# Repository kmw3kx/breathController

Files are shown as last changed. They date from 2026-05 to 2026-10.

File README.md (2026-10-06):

# Breath Controller

This is my personal repository for my wind controller project in development to catalog my work.

## Table of Contents
- [Daisy EVI Progress](#daisy-evi-progress)
- [Prospectus Submission for STS 4500, Summer 2026](#prospectus-submission-for-sts-4500-summer-2026)
- [Summer 2026 Personal Work](#summer-2026-personal-work)
- [Submission for Final Project, MUSI 4610, Spring 2026](#submission-for-final-project-musi-4610-spring-2026)
    - [Mapping](#mapping)
    - [Wiring](#wiring)
    - [**Sound**](#sound)
    - [CAD](#cad)
- [Future Improvements](#future-improvements)
- [Work Log](#work-Log)

## Daisy EVI Progress

### Summer 2026
7/20/26 - I have been continuing development of this project in between taking classes and working at my summer internship. The current model is running off of a daisy microcontroller. I have also been developing a 3D-printed needle valve to be able to more finely adjust back pressure of the instrument. There have been thoughts of creating custom pcb's for this project, but I am thinking of first making a prototype before trying to generate something that could be easily recreated. Hence, I am also trying other methods of fabrication beyond 3D printing, such as vacuum thermal forming, woodworking, and perfboard. I am also pivoting from an fsr to using a joystick attached to the mouthpiece, as there are issues with 3D printing food-safe mouthpieces.

(Post pic of prototype here)

The main confusion with using plug data is writing the custom .json file for the hardware integration. json doesn't have built-in comment functionality, so I had to really dig for the resources for this. See [here.](https://github.com/Wasted-Audio/hvcc/tree/develop/hvcc/generators/c2daisy/json2daisy/)

Unfortunately, it does not have support for an option to program in single-pin capacitive touch, so we'll need to trick it with pd code using an in/out pair. 

They also seem to use the digital pin numberings for analog ins, so 15 instead of A0.

Switch has a pullup resistor functionality built into it, but it is unclear if encoder does or not. 

I was having an issue with the analog inputs not printing to serial correctly when I was trying to code it in plugdata. The issue was that the 2 grounds needed to be tied together. 

I also wasn't able to get the cap touch working, so I decided to pivot back to using the mpr121. I originally was trying to avoid it since it's extra money, but... it will just make everything better. It saves the processing power & just simplifies everything.

[Here's](https://github.com/jonwaterschoot/plugdata-daisy-simple/tree/main) a good repo for daisy plugdata stuff.

[Here's](https://wasted-audio.github.io/hvcc/latest/generators/daisy/) the official stuff for daisy.

[Here's the current daisy_json guide](https://github.com/Wasted-Audio/hvcc/blob/develop/docs/generators/daisy_json.md)

I'm having some trouble getting the daisy to work with the MPR121 in plugdata. The patchsizes are starting to get very big, so I think I need to start using the bootloader.
https://community.daisy.audio/t/small-big-and-huge/9176/2

Working within MIDI seems to be more reliable than with serial. Press the boot button after resetting to keep the daisy in bootloader mode. I'm now having an issue with finding it as a midi device tho. Let me troubleshoot with my mpkmini.

8/4/26 - New day, new toolchain apparently. Printing is now working, so let's try and make something happen.

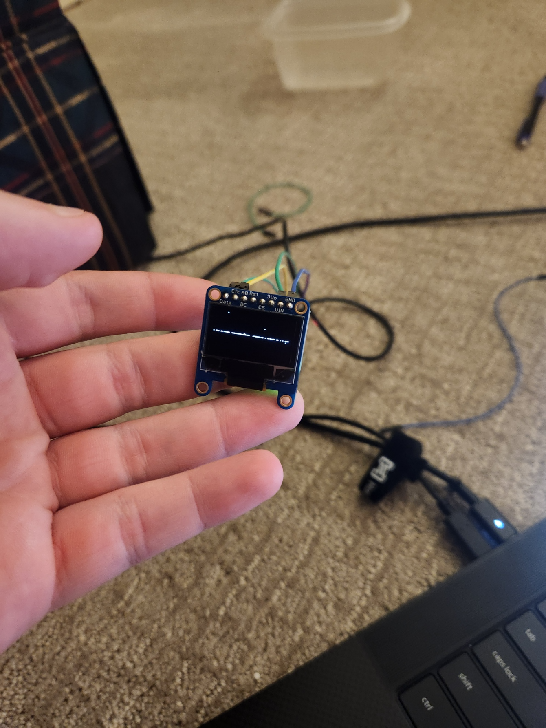
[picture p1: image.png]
DaisySeed3Pins


Idk why it's taken me this long to add this to my repo.

### Fall 2026

9/12/26 - Been busy with the start of the semester! Unfortunately, it is looking like this won't be my primary engineering capstone, but it's very likely I will be working on something instrument-related, which will give me skills that I could then incorporate into this project. I am also planning on continuing the development for this project this semester, with a hopeful completion of a DIY version available in December this year. My hope is that I can rope this in for my capstone group somehow, or at least be able to fulfill my prospectus topics, with a possible broadening to mapping sensor inputs to musical expression. We'll see. 

Anyways, I have a prototype done! 

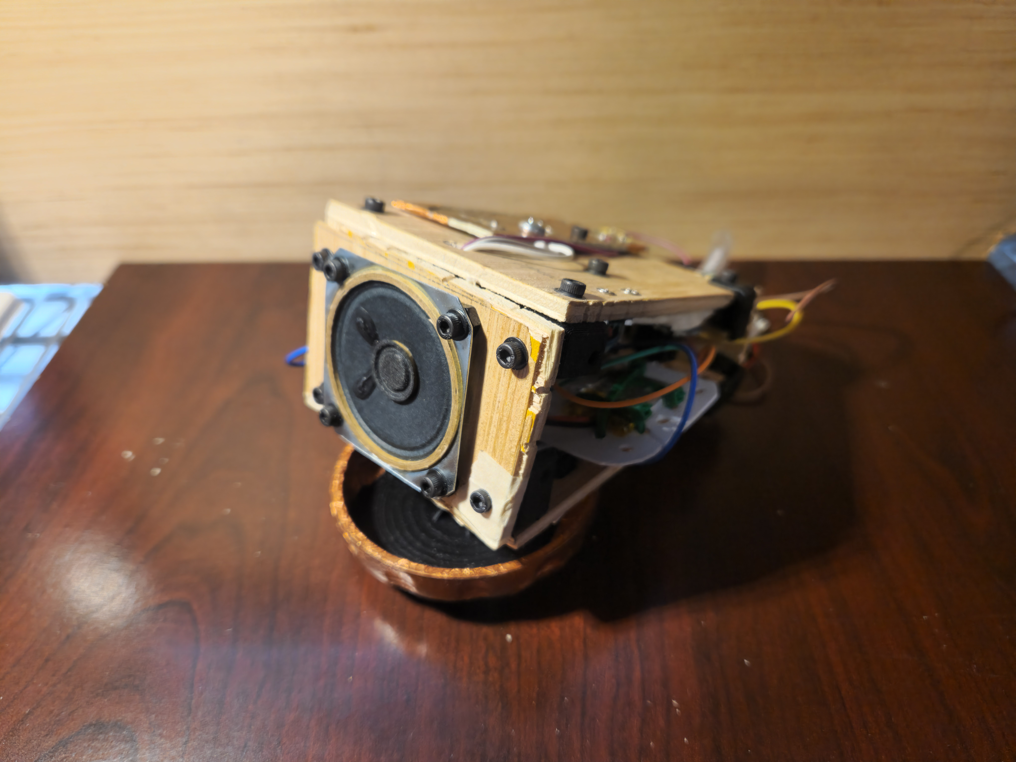
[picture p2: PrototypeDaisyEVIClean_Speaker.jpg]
PrototypeDaisyEVIClean_Speaker


I chose a completely different design process for this model. Since I was hoping it could be a capstone, I wanted to prioritize making a mockup by hand instead of getting trapped in CAD. 

I have been making some patches for my composition class, but I want to make a better functioning version so I can play it more consistently. I want to keep updating this repo, but I want to have more to show. 

I want to add a touch slider, better joystick mouthpiece assembly, and a display. I'm making progress on the display, but the OLED is still not working 100%
Oled

The next major update will likely come once this new hardware is done. Here's a sneak peek tho: 

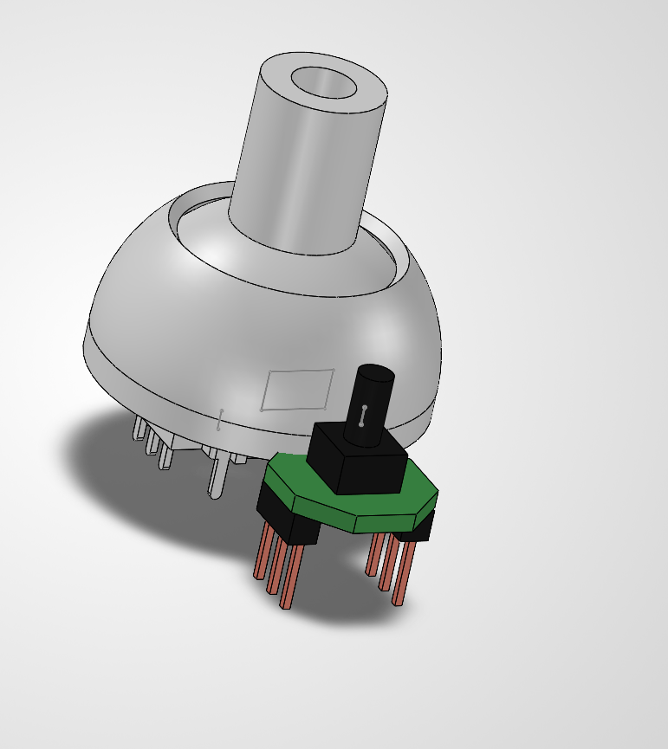
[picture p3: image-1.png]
sippuffJoy


## Prospectus Submission for STS 4500, Summer 2026

The PDF can be found under `/media` or by clicking [here](media/ProspectusFINAL_Kammauff.pdf)

The Prospectus is a graduation requirement for the engineering school @ UVA, but doesn't guarantee that the corresponding capstone will be taken on, due to it being a group project. I am hopeful, but I won't know come fall.

(Update: my capstone is not this unfortunately. It is still being clarified, but it will likely be a electric guitar)

## Summer 2026 Personal Work

The project is continuing development during these summer weeks between semesters and other personal projects. I am learning KiCAD in order to develop better PCB's for the components. Development is being moved over to the daisy seed microcontroller, and will consist of multiple modules, instead of the single board from the last iteration. Currently, I am waiting on the Wilson Maker Space mill to be back up in 'early July' before any more production continues with this project. It has proven to be a large undertaking, but I am hoping to have a new prototype come fall. 

## Submission for Final Project, MUSI 4610, Spring 2026
This project was inspired by [this post on hackaday.io](https://hackaday.io/project/25756-diy-evi-style-windcontroller)  that created a EVI-style breath controller. As such, I use a lot of the same components that he does. 

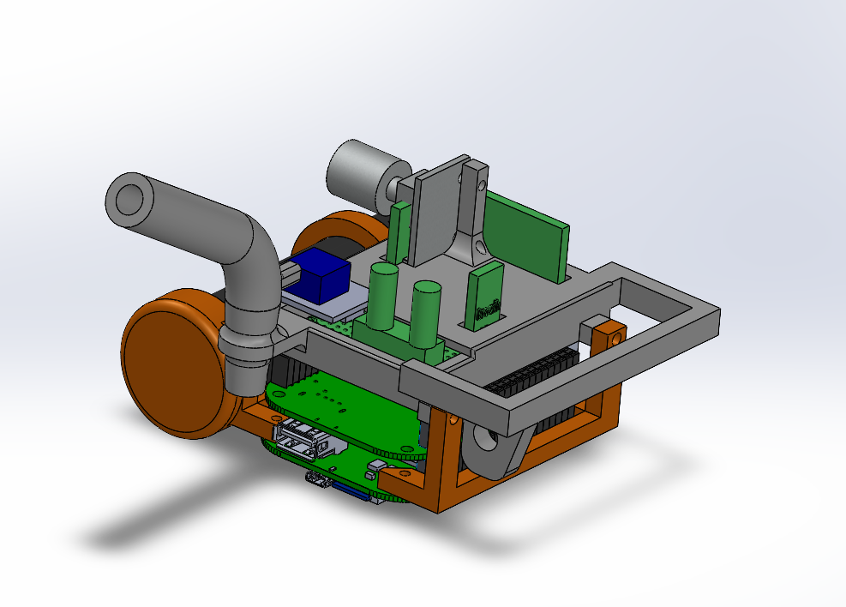
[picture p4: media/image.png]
CAD Rendering of the project


The basic premise of the instrument is to give brass players access to easily controlling electronic sounds. It uses a pressure sensor connected to a lead pipe in order to determine the breath pressure of the player. The two potentiometers can be used to adjust how the breath signal is interpreted; the one on the left adjusts the cutoff threshold, and the one on the right controls the power mapping. It also has a 'valve block' to allow the player to use the same fingering system developed for brass instruments (1st Valve moves the pitch down a whole step, 2nd Valve down a half step, and 3rd Valve down a minor 3rd). However, a problem instantly arrives: brass musicians usually rely on playing in the harmonic partials of a physical tube in order to expand the range greater than just the tritone provided. So, we need additional controls. I decided on using an encoder as a way to toggle between octaves with a easy motion that still provides a clear source of feedback (clicking with each increment). This worked, but it still wasn't fully chromatic. I experimented with adding a 4th and 5th valve (operated by the pinky and thumb respectively, which lowered and raised the pitch by a 4th), which allows the instrument to be fully chromatic (and have multiple alternate fingerings to allow for more flexibility in tricky passages across the octave split), but this experimentation was still very clunky, since most brass instruments with more than 3 valves start to become less standard and more a product of tuning constraints; most brass players are the most comfortable just using the first 3 valves. So, I decided on a system where the encoder actually start alternating between Bb and F in octaves; the 2nd and 3rd harmonic partial that brass normally starts in. This allows the instrument to be fully chromatic, yet still have the octave shifting feature where each note in any octave is played with the same fingering.
### Mapping
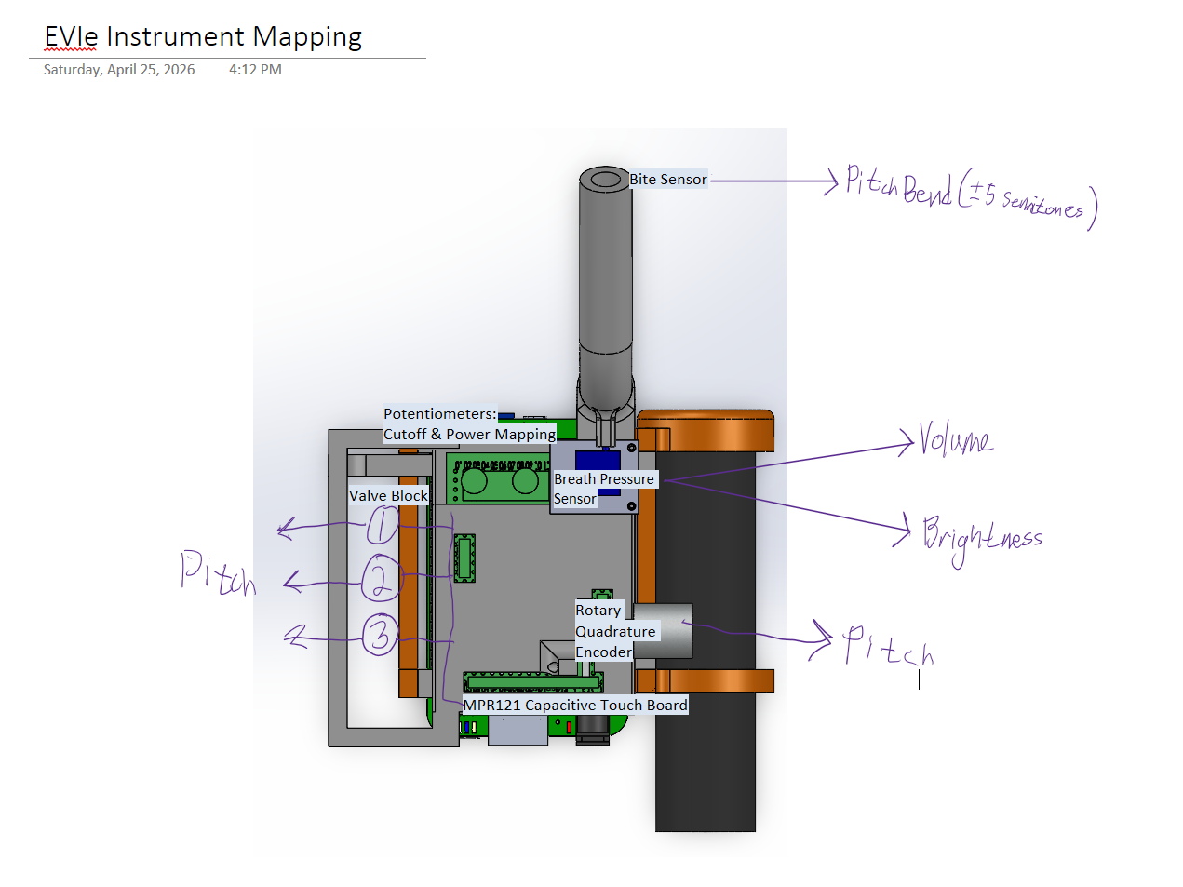
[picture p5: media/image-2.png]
Mapping

### Wiring
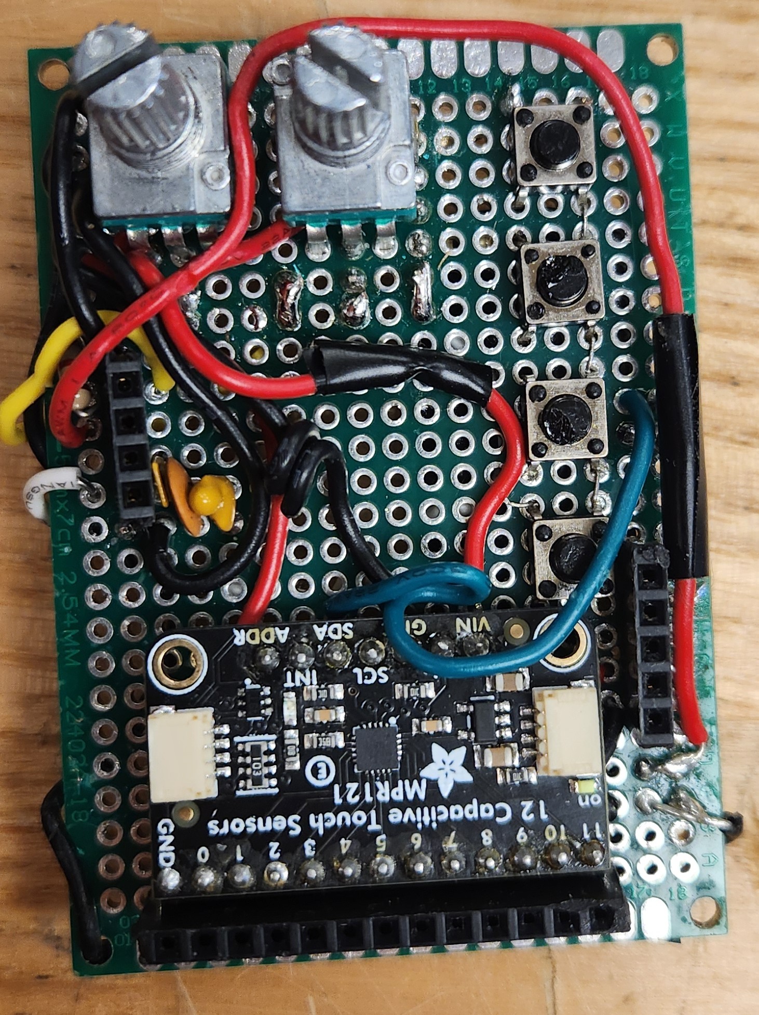
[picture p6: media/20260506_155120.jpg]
Front of breakout board


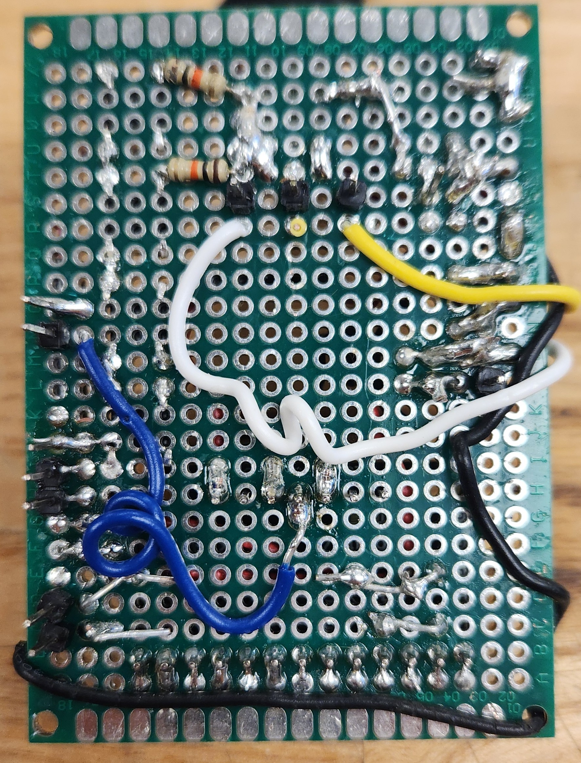
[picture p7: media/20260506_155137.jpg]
back


The valves are a combination of stranded core soldered to solid core. I used lock washers to ensure a very sturdy connection between the stranded wire and the bolts I was using for the capacitive touch valves. They are plugged into their corresponding number on the MPR121 (1-5), where 5 is the thumb. The encoder plugs in directly to the 5 female sockets on the right, with the knob facing away. The breath sensor is plugged into the ground port on the MPR, and the white wire side of the 4 female sockets, w/ V_in going to the inner one, and V_out to the outer. If the bite sensor is to be used, it is plugged into the upper 2 sockets; polarity doesn't matter. 

### Sound
The sound of the instrument can be swapped out in the code by attaching the frequency and breath lines into where `BrassLead` currently is. `simpleSound.pd` and `SubSynth.pd` are alternative sound modules. 

`BrassLead.pd` uses a simple FM algorithm to create a sound that increases in brightness w/ respect to breath input.
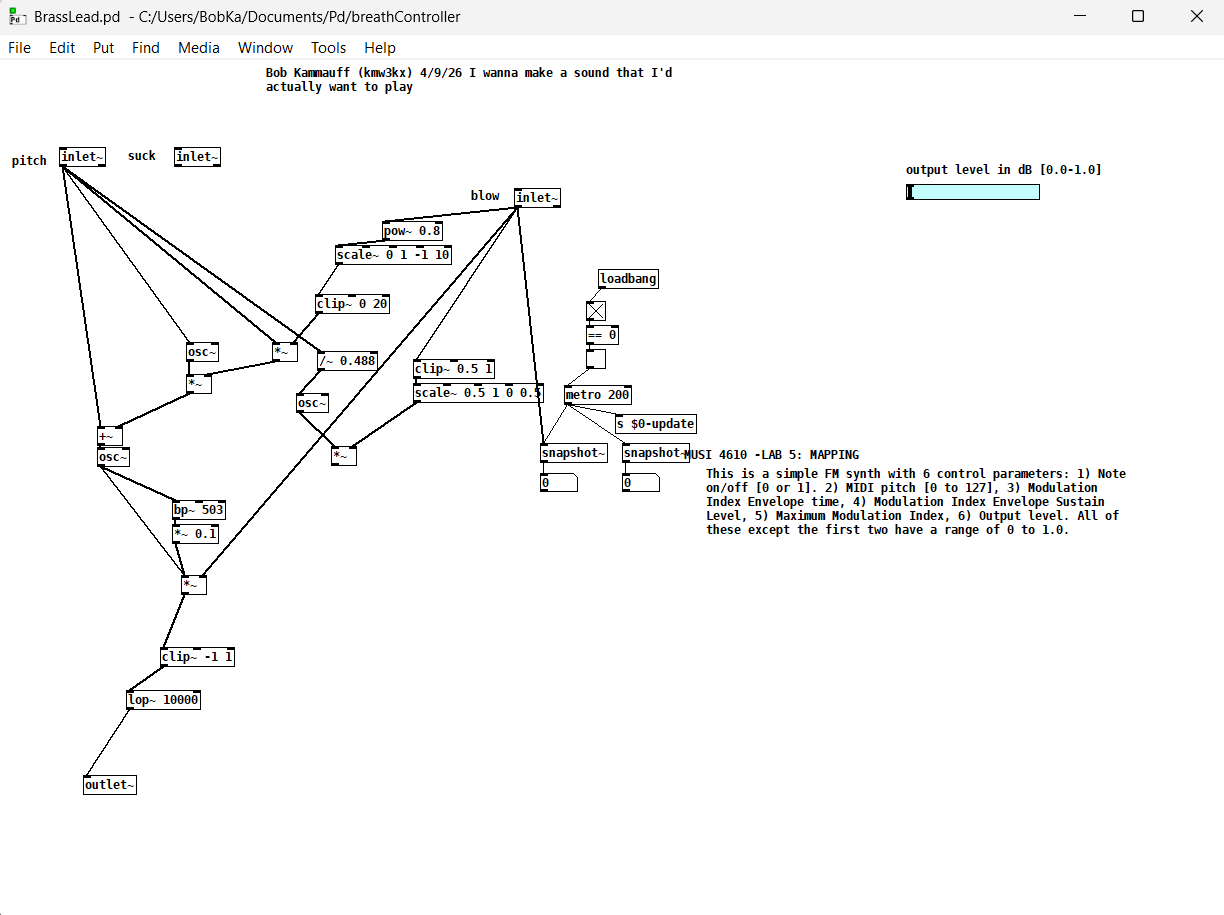
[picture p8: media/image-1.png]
BrassLead.pd


You can find a link to a video of the instrument being played [here.](https://youtube.com/shorts/NqKi1nieuh8)

### CAD
All CAD files that I used while developing this prototype can be found [here.](https://myuva-my.sharepoint.com/:f:/g/personal/kmw3kx_virginia_edu/IgA0IbZReZuJRZx14ltvIYuoAS6oU6uEX7or4lSNlIzHq_s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)

### Future Improvements
There are a ton of improvements that are possible with this instrument and implementation that I am planning on pursuing looking forward:

- Added Features
    - I had started implementing a 'bite sensor' for the instrument using a FSR attached to a small length of 5/8" OD silicone tubing. This was mapped to pitch bend. The tubing acted as a good mouthpiece, as well as giving acting as a spring for the bite sensor to 'bounce back.' I think that I was able to get far enough with it to qualify as a prototype, but the FSR had a very awkward resistance curve(seen below), and it was hard to figure out how to scale it appropriately. The current implementation uses a static resistor (1kOhm I think) to put the instrument at around concert pitch.
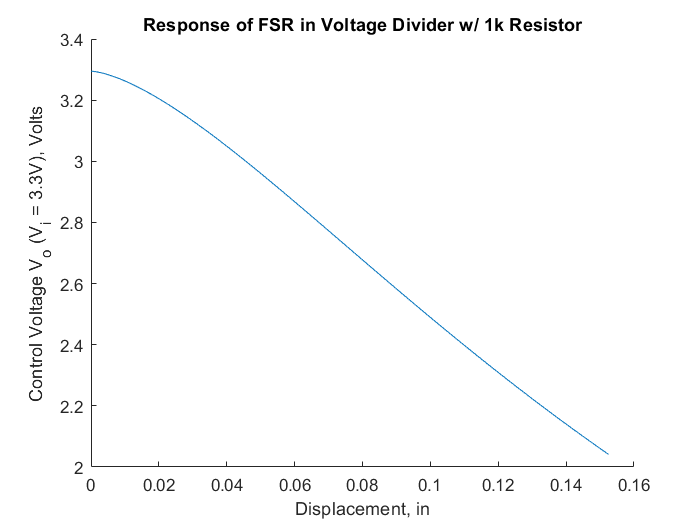
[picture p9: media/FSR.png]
FSR
    
- I would love for this to be able to both act as a MIDI controller and to be able to adjust settings and presets with a MIDI controller (e.g. to adjust the sound). SubSynth.pd has this MIDI controller connection already built-in.
- Adjustments to sound, control, etc. 

>Project Report:  Due Friday May 10 at 11pm on Canvas.
>Submit the following materials:
>- Your Pd code, and any resources used in the Bela project.
>- A video of your instrument being performed.
>- A report, describing how your instrument works, what your design goals were, what you learned from building it, and what you might change or do differently if you built it again. The report should include a description and diagrams of the user parameters, the synthesis algorithm, and, importantly, the mapping.

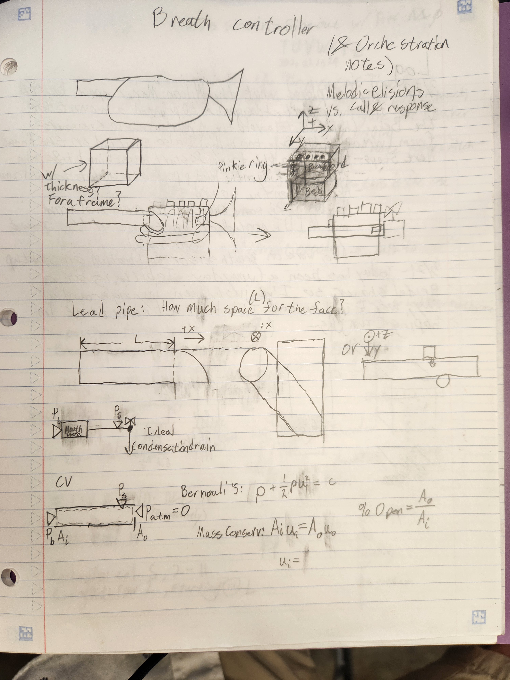
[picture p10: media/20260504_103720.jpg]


## Work Log

### 3/17/26

I am submitting this README as my text file for the `Exercise 3 - Two-Button++ Bela Instrument` assignment. My instrument is a prototype of an EVI that I hope to make into my final project. It takes readings from a pressure sensor, a MPR121 Capacitive Touch board, and a rotary encoder and lets you play it like you would play a trumpet. The sound is just a simple sine wave (& saw wave when suctioned), but it demonstrates the possibilities of using breath for audio synthesis.

### 3/20/26
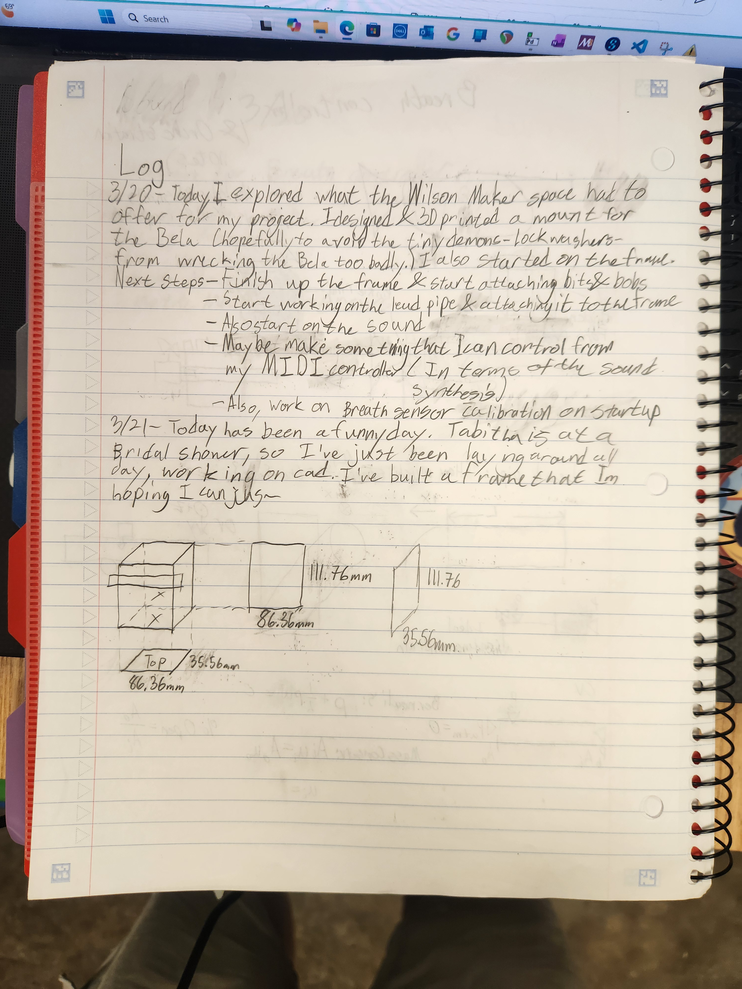
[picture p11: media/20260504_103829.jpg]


### 4/22/26
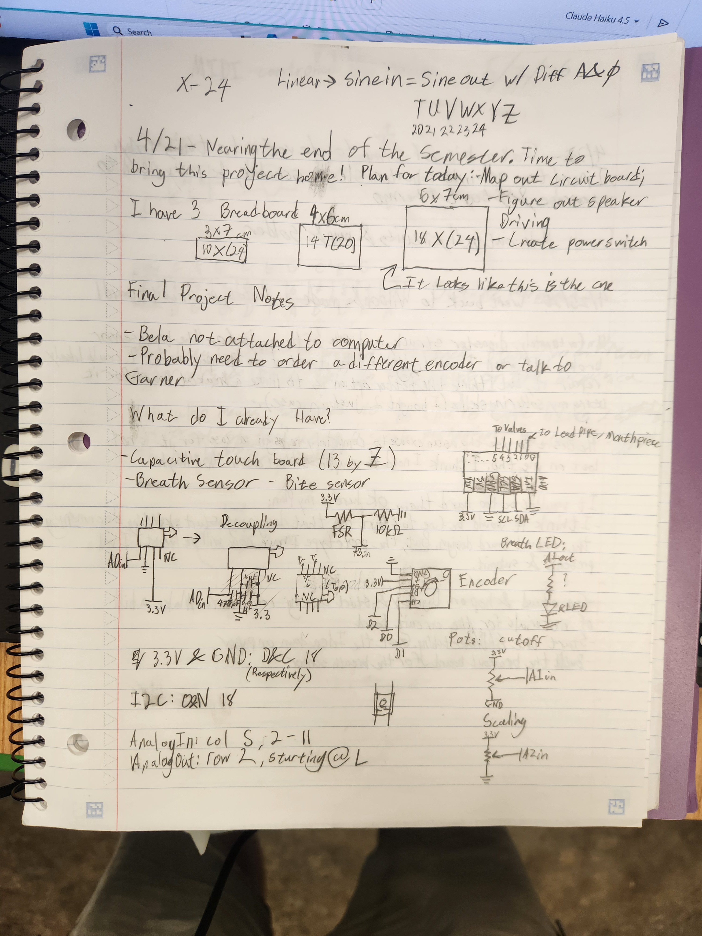
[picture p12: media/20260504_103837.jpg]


### 4/25/26
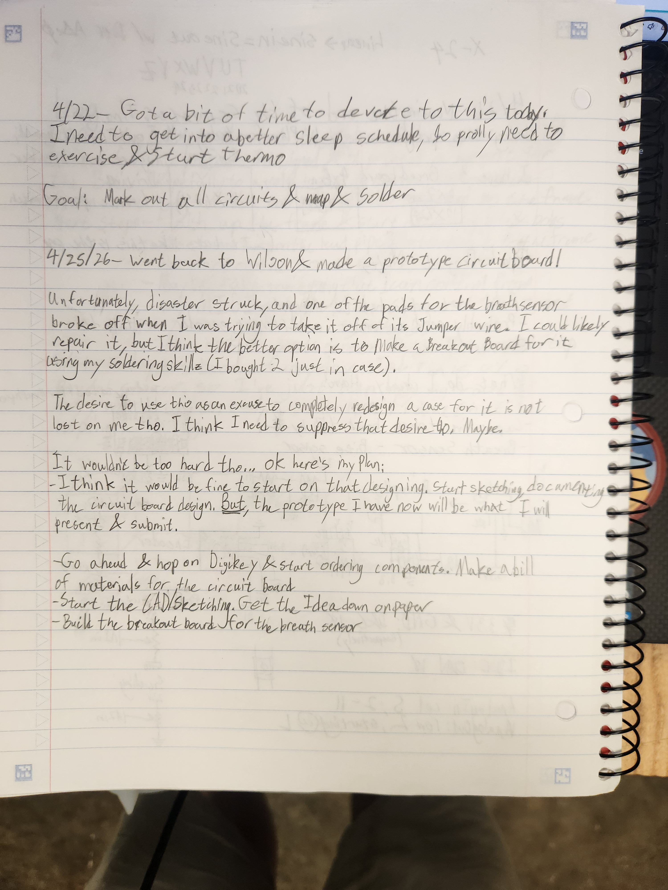
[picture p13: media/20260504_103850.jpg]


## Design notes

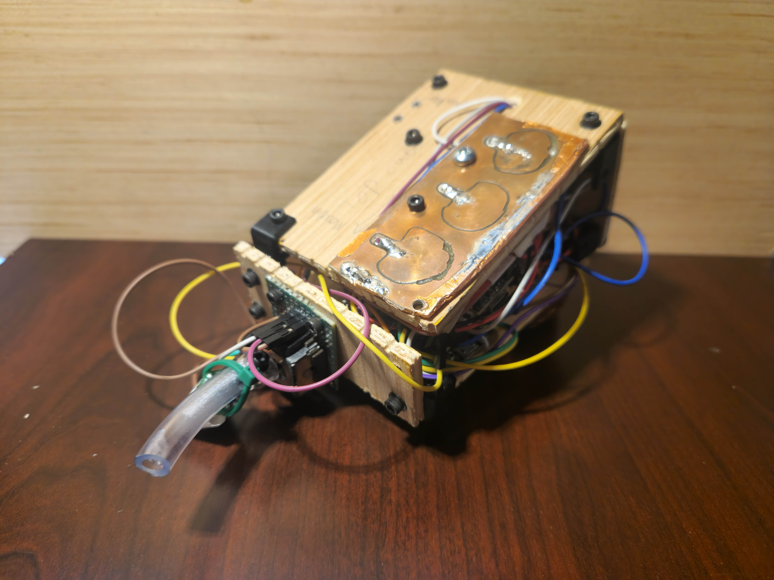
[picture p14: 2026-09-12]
media/PrototypeDaisyEVIClean_Front.jpg

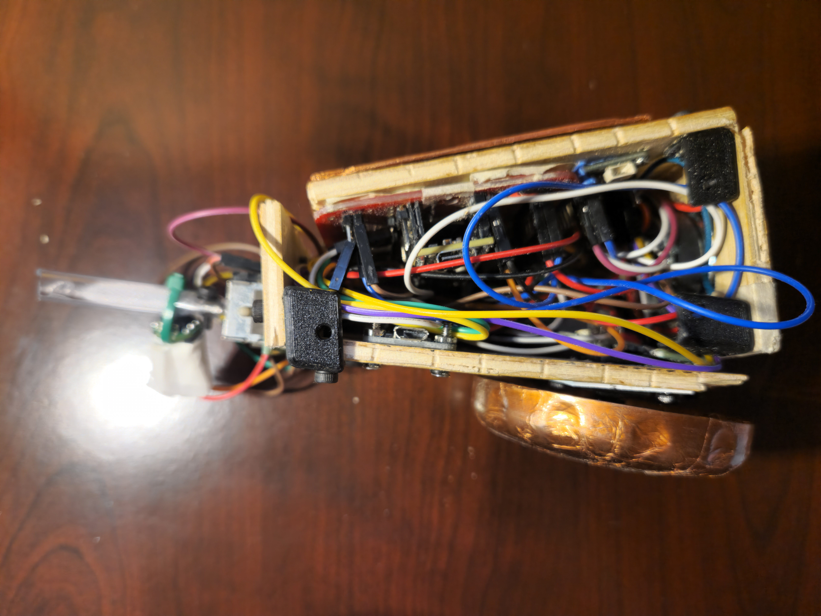
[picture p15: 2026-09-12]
media/PrototypeDaisyEVIClean_Right.jpg

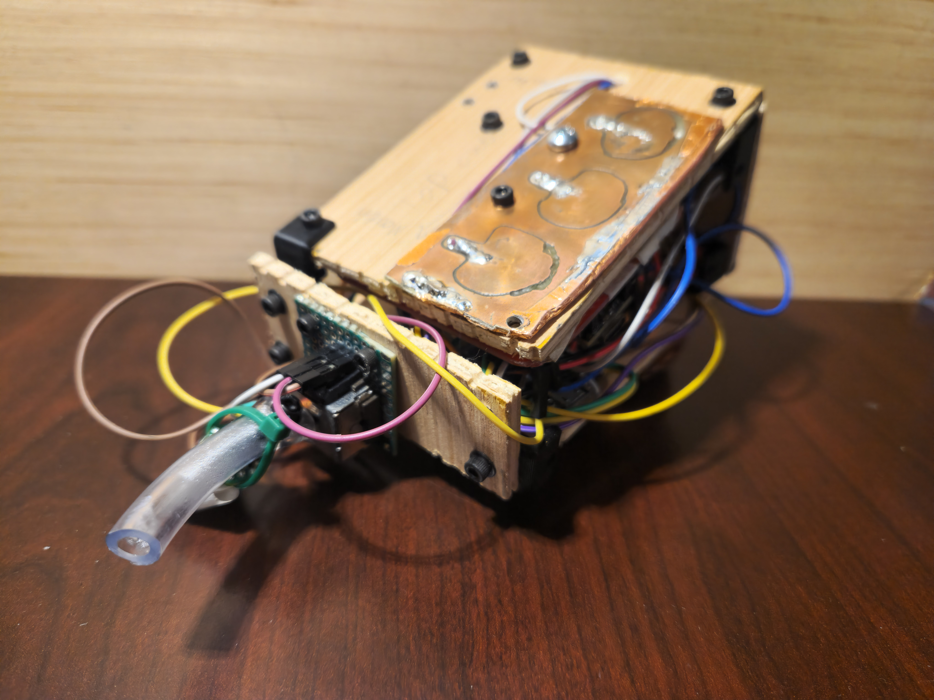
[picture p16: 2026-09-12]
media/PrototypeDaisyEVICleanFront(2).jpg

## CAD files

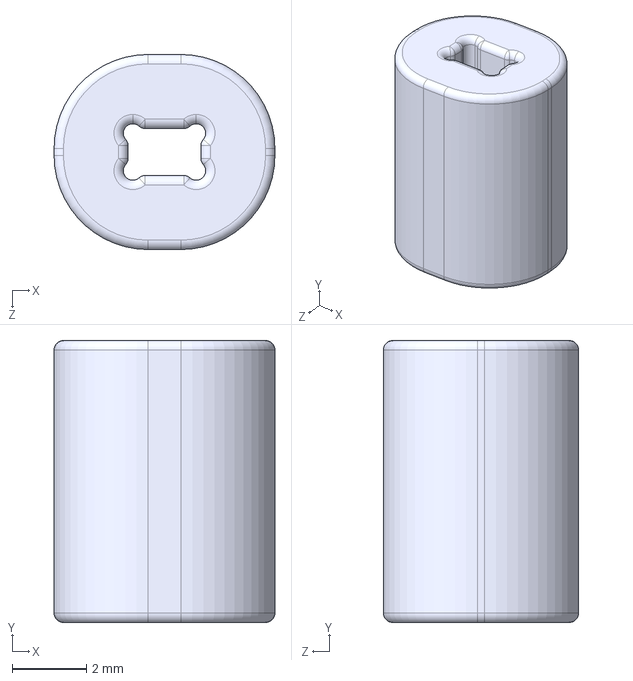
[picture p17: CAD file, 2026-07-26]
daisy/CAD/JoyStickCap.STEP
5.97 x 7.62 x 5.27 mm

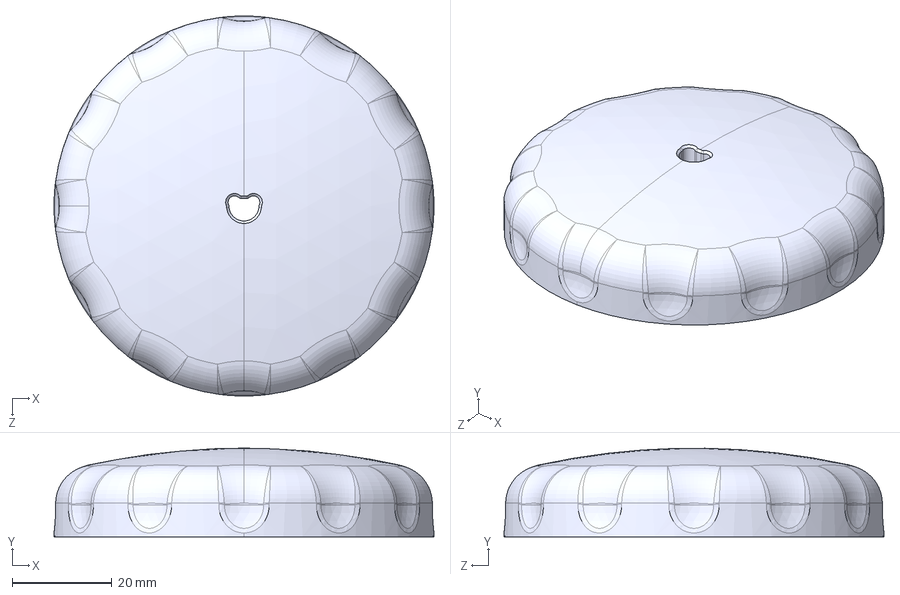
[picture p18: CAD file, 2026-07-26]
daisy/CAD/EncoderKnob.STEP
76.2 x 17.8 x 76.2 mm

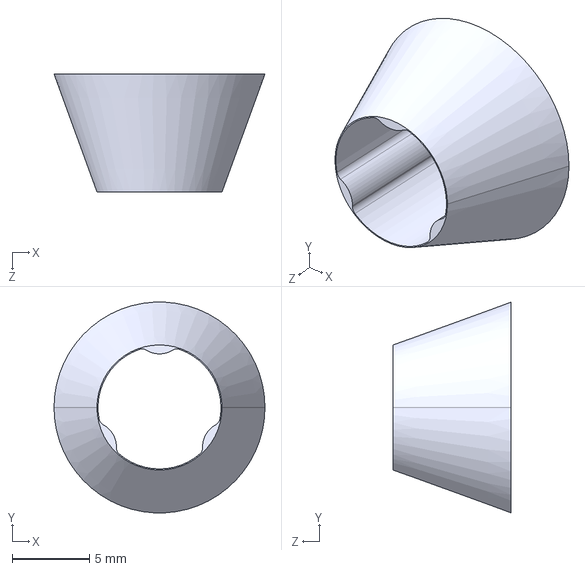
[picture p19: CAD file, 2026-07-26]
daisy/CAD/NeedleValveStopper.STEP
13.6 x 13.6 x 7.62 mm

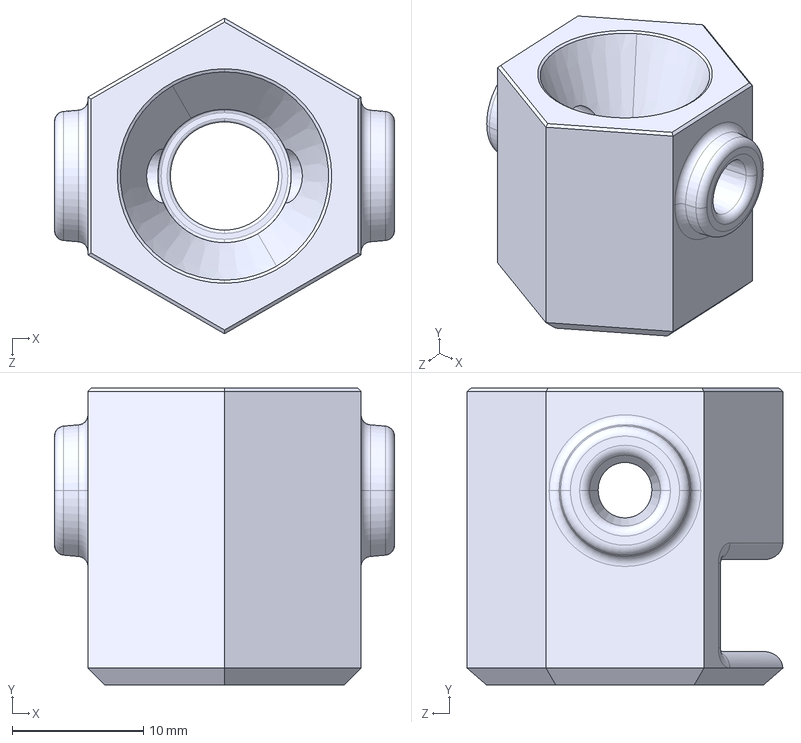
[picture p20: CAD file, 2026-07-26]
daisy/CAD/NeedleValve_Body.STEP
25.9 x 22.6 x 24.1 mm

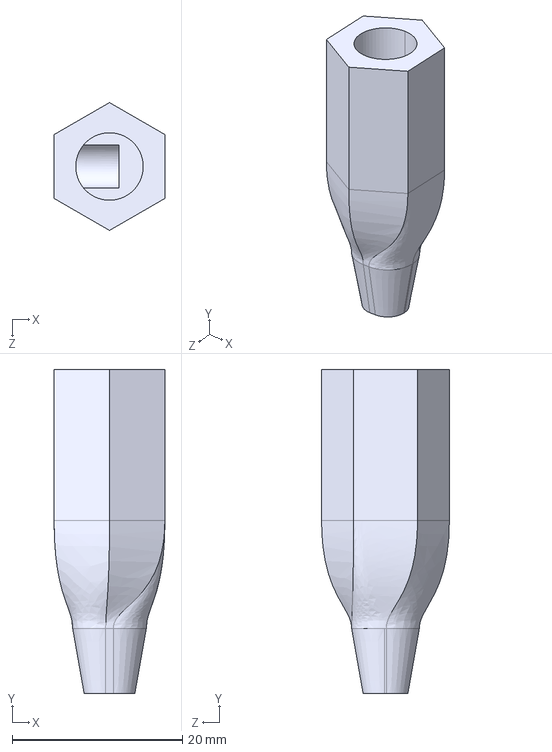
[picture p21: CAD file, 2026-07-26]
daisy/CAD/JoyStickCapV2.STEP
13.0 x 38.1 x 15.0 mm

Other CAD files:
daisy/CAD/EncoderKnob.SLDPRT
daisy/CAD/JoyStickCap.SLDPRT
daisy/CAD/NeedleValveStopper.SLDPRT
daisy/CAD/NeedleValve_Body.SLDPRT

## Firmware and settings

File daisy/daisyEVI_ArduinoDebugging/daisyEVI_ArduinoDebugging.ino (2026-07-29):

// daisy EVI debugging code
// 7/23/26
// kmw3kx
// Written by Copilot, edited by Bob

// -----------------------------
// Pin assignments
// -----------------------------

// Analog sensors
const int analogPins[3] = {A1, A2, A3}; // breath & joy

// Capacitive sensors (each uses 2 pins: send + receive)
struct CapPins {
  int sensePin;
  int pumpPin;
};
CapPins cap[3] = { // (100k and 1k order)
  {13, 9},   // cap sensor 1, grn (D13) & gry(D9)
  {12, 14},   // cap sensor 2, ylw (D11) & red (D14) 
  {11, 10}   // cap sensor 3, wt  (D10) & Wt (D12)
};

// Encoder
#define ENC_CLK 5
#define ENC_DT  4
#define ENC_SW  3

volatile long encoderCount = 0;
volatile bool encoderMoved = false;

// -----------------------------
// Setup
// -----------------------------
void setup() {
  Serial.begin(115200);

  // Analog pins
  for (int i = 0; i < 3; i++) {
    pinMode(analogPins[i], INPUT);
  }

  // Capacitive sensor pins
  for (int i = 0; i < 3; i++) {
    pinMode(cap[i].sensePin, INPUT);
    pinMode(cap[i].pumpPin, OUTPUT);
  }

  // Encoder pins (external pull-ups assumed)
  pinMode(ENC_CLK, INPUT_PULLUP);
  pinMode(ENC_DT, INPUT_PULLUP);
  pinMode(ENC_SW, INPUT_PULLUP);

  attachInterrupt(digitalPinToInterrupt(ENC_CLK), encoderISR, CHANGE);
  attachInterrupt(digitalPinToInterrupt(ENC_DT),  encoderISR, CHANGE);
}

// -----------------------------
// Capacitive sensing function
// -----------------------------
// Measures charge time on sensePin.
uint16_t readCap(int sensePin, int pumpPin) {
  uint16_t count = 0;

  // Step 1: Discharge pad through pumpPin
  digitalWrite(pumpPin, LOW);
  delayMicroseconds(100);
  while (digitalRead(sensePin) == HIGH) {
    count++;
    if (count > 65000) break;
  }

  // Step 2: Charge pad through pumpPin
  digitalWrite(pumpPin, HIGH);

  // Step 3: Count until sensePin reads HIGH
  while (digitalRead(sensePin) == LOW) {
    count++;
    if (count > 65000) break;
  }

  return count;
}
// int readCapacitive(int sendPin, int recvPin) {
//   int count = 0;

//   // 1. Discharge the pad by pulling sendPin LOW briefly
//   digitalWrite(sendPin, LOW);
//   delayMicroseconds(5);

//   // 2. Begin charging
//   digitalWrite(sendPin, HIGH);

//   // 3. Count until recvPin rises
//   while (digitalRead(recvPin) == LOW && count < 3000) {
//     count++;
//   }

//   return count;
// }


// -----------------------------
// Encoder interrupt
// -----------------------------


void encoderISR() {
  static int lastCLK = digitalRead(ENC_CLK);

  int clkState = digitalRead(ENC_CLK);
  int dtState  = digitalRead(ENC_DT);

  // Only act on CLK changes
  if (clkState != lastCLK) {
    if (dtState != clkState) encoderCount++;   // clockwise
    else encoderCount--;                       // counter‑clockwise
    encoderMoved = true;
  }

  lastCLK = clkState;
}

// -----------------------------
// Main loop
// -----------------------------
void loop() {
  // Read analog sensors
  int analogVals[3];
  for (int i = 0; i < 3; i++) {
    analogVals[i] = analogRead(analogPins[i]);
  }

  // Read capacitive sensors
  int capVals[3];
  for (int i = 0; i < 3; i++) {
    capVals[i] = readCap(cap[i].sensePin, cap[i].pumpPin);
  }

  // Read encoder button
  bool buttonPressed = (digitalRead(ENC_SW) == LOW);

  // Print everything in one line
  Serial.print("A:");
  Serial.print(analogVals[0]); Serial.print(",");
  Serial.print(analogVals[1]); Serial.print(",");
  Serial.print(analogVals[2]);

  Serial.print("  C:");
  Serial.print(capVals[0]); Serial.print(",");
  Serial.print(capVals[1]); Serial.print(",");
  Serial.print(capVals[2]);

  Serial.print("  ENC:");
  Serial.print(encoderCount);

  Serial.print("  BTN:");
  Serial.print(buttonPressed ? 1 : 0);

  Serial.println();

  delay(10);
}

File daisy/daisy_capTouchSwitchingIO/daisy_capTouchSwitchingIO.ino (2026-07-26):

// Basic capacitive sensing on a single Arduino pin
// No external libraries required

const int sensePin = 13;     // Touch electrode
const int sendPin  = 9;     // Drive pin (optional but improves stability)

long readCapacitance() {
  long count = 0;

  // 1. Discharge the sense pin
  pinMode(sensePin, OUTPUT);
  digitalWrite(sensePin, LOW);
  delayMicroseconds(5);

  // 2. Charge through sendPin
  pinMode(sensePin, INPUT);        // High impedance
  digitalWrite(sendPin, HIGH);     // Start charging the electrode

  // 3. Count until the sense pin reads HIGH
  while (digitalRead(sensePin) == LOW) {
    count++;
    if (count > 30000) break;      // Safety cap
  }

  // 4. Discharge again
  pinMode(sensePin, OUTPUT);
  digitalWrite(sensePin, LOW);

  return count;
}

void setup() {
  Serial.begin(115200);
  pinMode(sendPin, OUTPUT);
  digitalWrite(sendPin, LOW);
}

void loop() {
  long cap = readCapacitance();
  Serial.println(cap);
  delay(10);
}

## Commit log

2026-03-12 Used ultrasonic dist wrapper as base for more complete code
2026-03-21 Added breath sensor calibration and MIDI cc control. Started on physical modeling
2026-03-24 Added 5th thumb valve, plus cleaned up some bugs in _main.pd
    [render.cpp]
2026-03-28 Made fun Synth w/ Filters and a delay line
2026-04-10 All sensors work, as well as LED; Appears that logic is broken. Also, I think the brass lead is too complex for the board.
2026-07-20 Started moving daisy work over into the repo
    [daisyEVI.kicad_pcb, daisyEVI.kicad_sch]
2026-07-26 Did Work on CAD; Now coding time
    [EncoderKnob.SLDPRT, EncoderKnob.STEP, JoyStickCap.SLDPRT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]
2026-07-26 Started on the json config; daisy prints a constant
2026-07-27 Tried using AI agent to look thru the compiled C. Hopefully didn't wreak havoc on my repo
    [ADCMulti.cpp, ADCMux.cpp, Encoder.cpp]
2026-07-29 Still Trying to debug the analog issue
    [ADCMulti.cpp, ADCMux.cpp, Encoder.cpp]
2026-07-30 STILL trying to fix analog in error. Tempted to pivot to C++, or work on the cap sensing in PD
    [ADCMulti.cpp, ADCMux.cpp, Encoder.cpp]
2026-08-01 Started working on the mpr and tying the sensors together. Need to start using the bootloader due to patch size.
2026-08-15 cleaned up repo
    [TestCNC_JoyStick.kicad_pcb, TestCNC_JoyStick.kicad_sch, TestCNC_PerfBoard.kicad_pcb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]
2026-09-08 Add new Pure Data patches for touch and sound interaction
    - Created TouchPrint.pd for touch data processing and logging.
    - Added TouchtoSoundTest.pd to test sound output based on touch input.
    - Introduced daisyevi_leadtone.pd for lead tone generation with various controls.
    - Updated daisyevi_testtone.pd to enhance tone generation and input handling.
    - Modified dreamer_mpr_test.pd for calibration testing with touch input.
    - Adjusted protodaisyevi.json to correct pin assignments for analog controls.
    - Added daisypin.png for visual representation of Daisy pin layout.
2026-09-12 Update README and add prototype images for Daisy EVI project
2026-09-17 Add new Pure Data patches for bob_scale and sampleRateTest
